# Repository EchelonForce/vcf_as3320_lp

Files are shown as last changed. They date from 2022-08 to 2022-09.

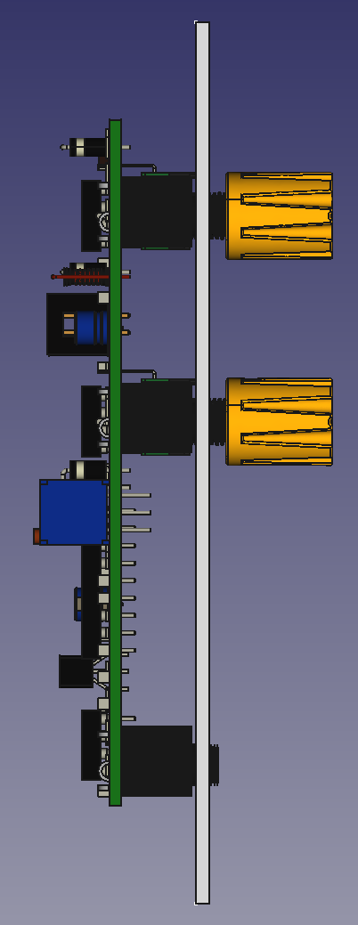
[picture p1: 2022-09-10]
front_panel_v1/render3.png

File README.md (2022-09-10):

# Eurorack Low Pass VCF AS3320

This is a design for a eurorack low pass VCF using the AS3320 VCF chip.

Full writeup here: https://www.robotdialogs.com/2022/09/eurorack-vcf-module-low-pass-filter.html

This work is licensed under a Creative Commons Attribution-NonCommercial-ShareAlike 4.0 International License. https://creativecommons.org/licenses/by-nc-sa/4.0/

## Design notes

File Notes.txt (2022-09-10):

https://electricdruid.net/multimode-filters-part-1-reconfigurable-filters/
https://electricdruid.net/multimode-filters-part-2-pole-mixing-filters/

Full datasheet: https://www.bustedgear.com/images/datasheets/CEM3320.pdf

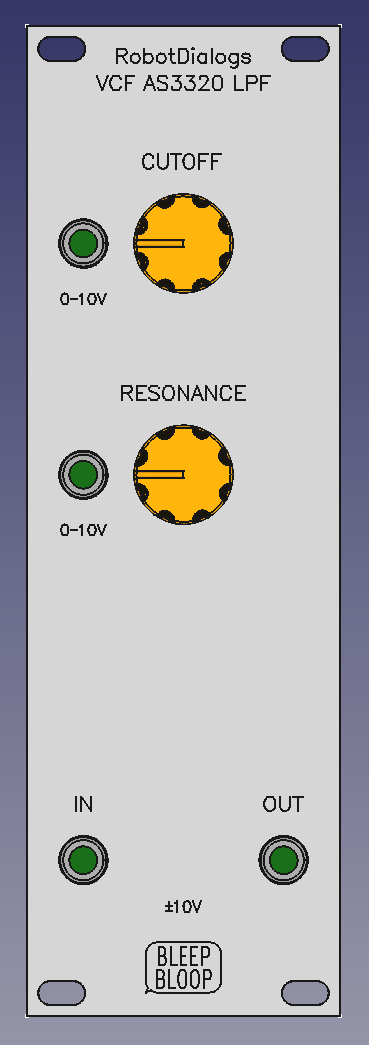
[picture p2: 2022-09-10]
front_panel_v1/render1.png

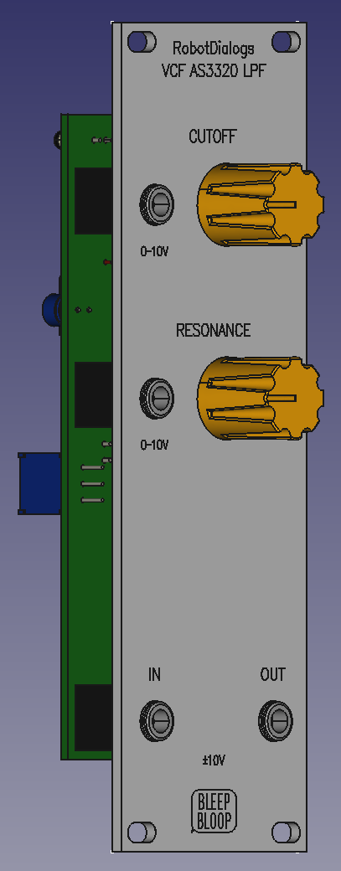
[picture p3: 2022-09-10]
front_panel_v1/render2.png

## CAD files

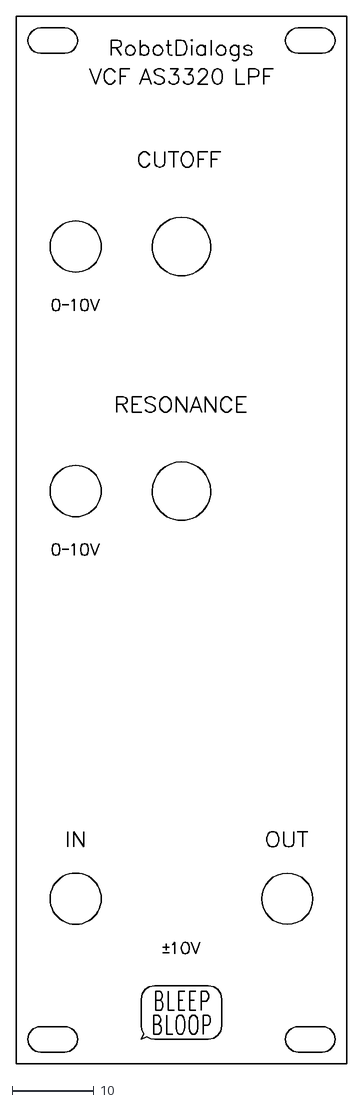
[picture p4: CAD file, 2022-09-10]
front_panel_v1/vcf_as3320_lpf_v1_front_panel_v1_engraving.dxf
40.5 x 128.4

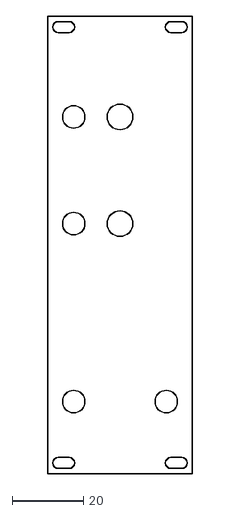
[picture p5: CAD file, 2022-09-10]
front_panel_v1/vcf_as3320_lpf_v1_front_panel_v1_no_engraving.dxf
40.6 x 128.5

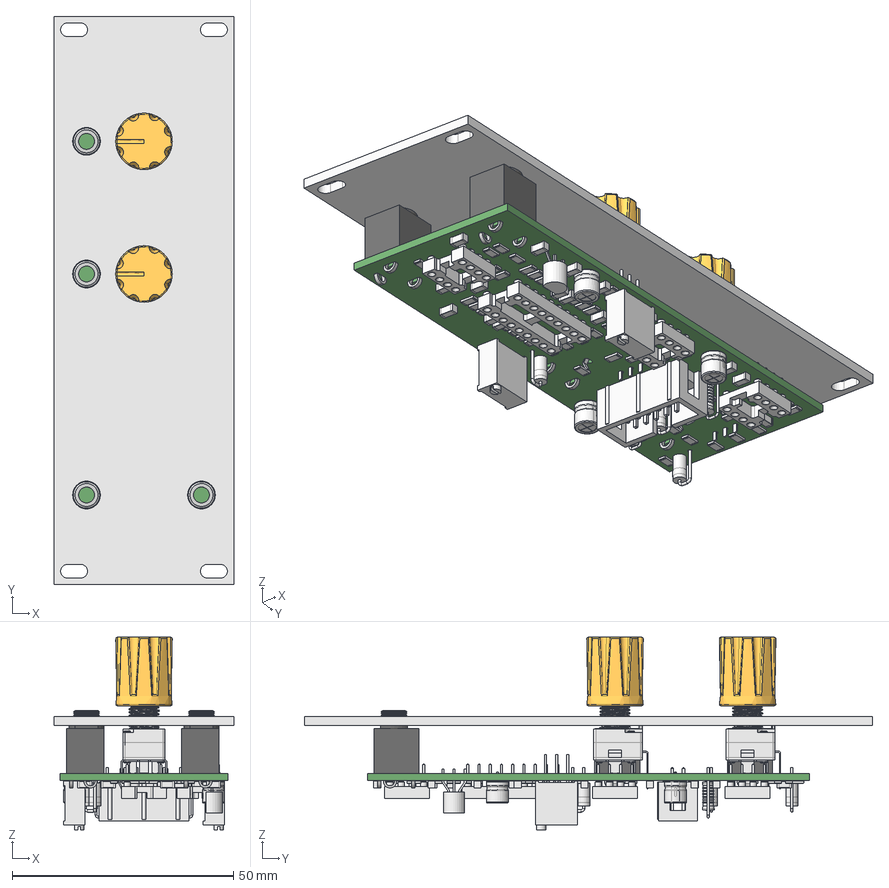
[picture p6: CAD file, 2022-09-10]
front_panel_v1/vcf_as3320_lpf_v1_front_panel_v1.FCStd
40.6 x 128.5 x 43.5 mm
vcf_as3320_lpf_v1 PCB

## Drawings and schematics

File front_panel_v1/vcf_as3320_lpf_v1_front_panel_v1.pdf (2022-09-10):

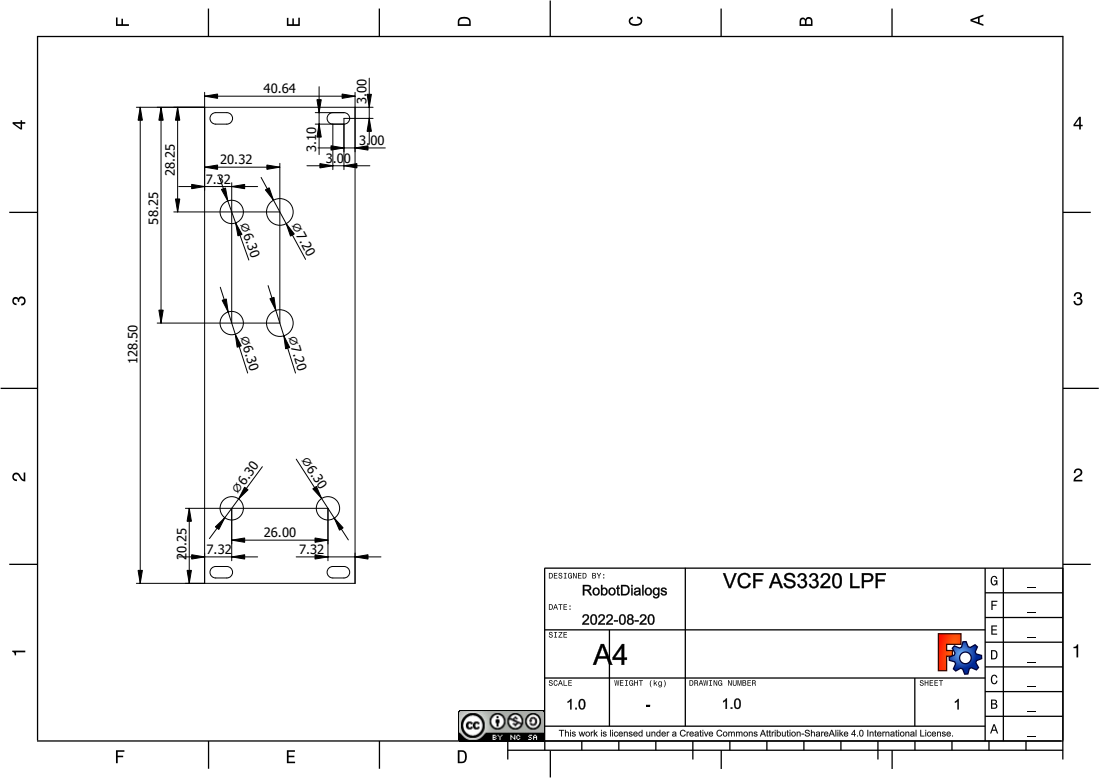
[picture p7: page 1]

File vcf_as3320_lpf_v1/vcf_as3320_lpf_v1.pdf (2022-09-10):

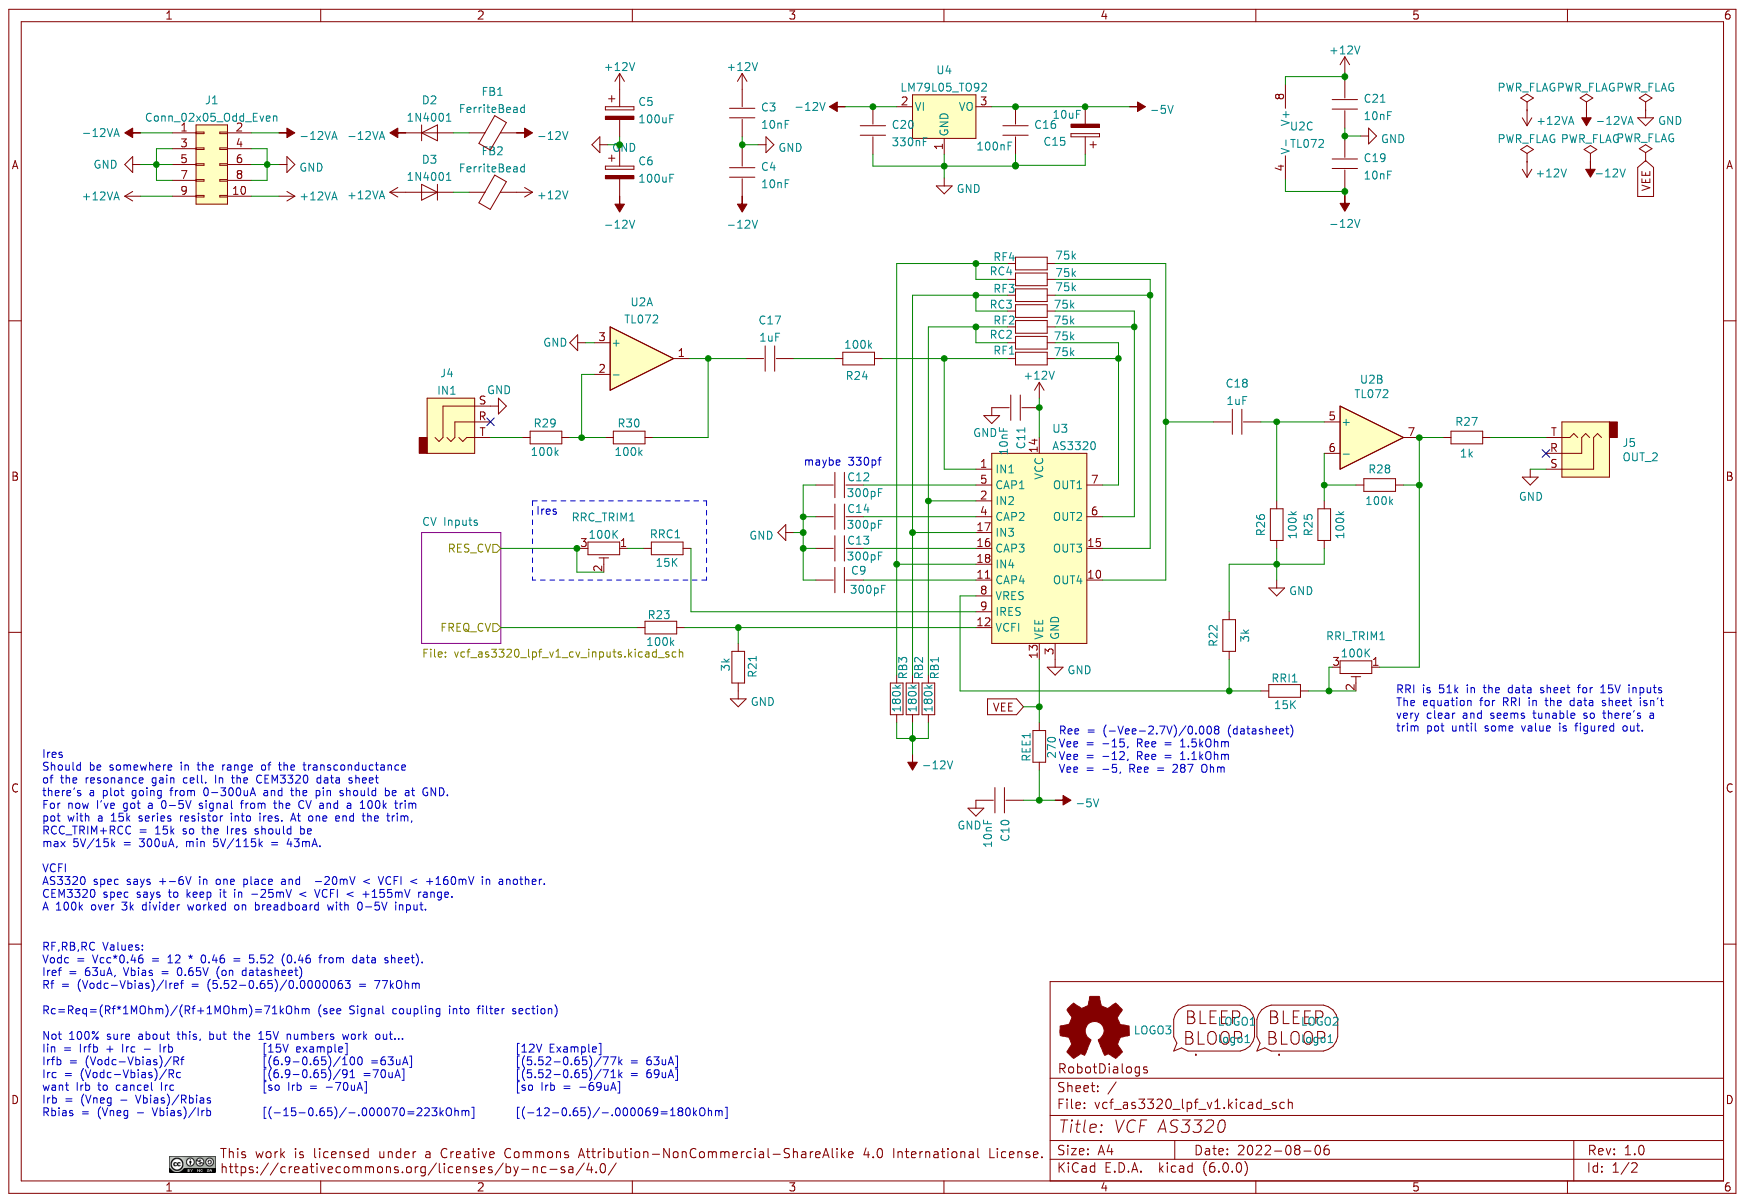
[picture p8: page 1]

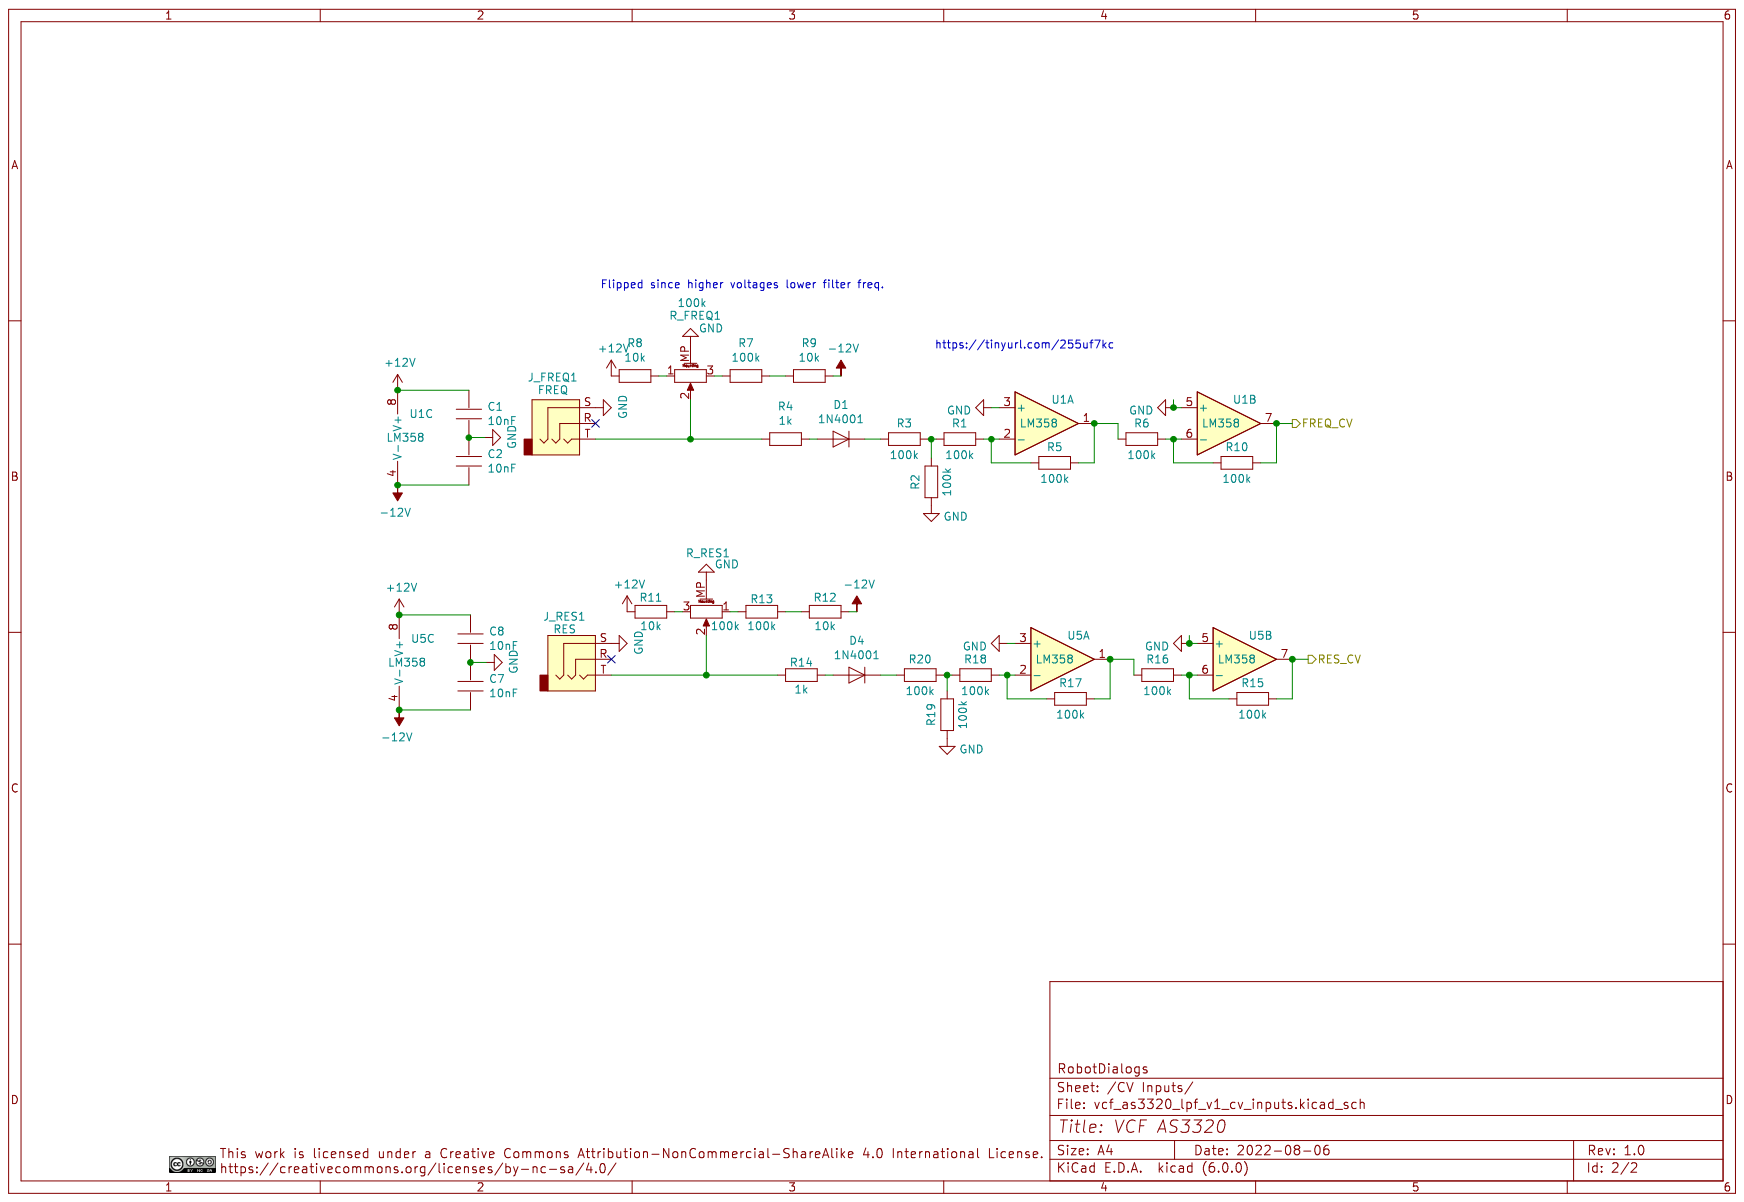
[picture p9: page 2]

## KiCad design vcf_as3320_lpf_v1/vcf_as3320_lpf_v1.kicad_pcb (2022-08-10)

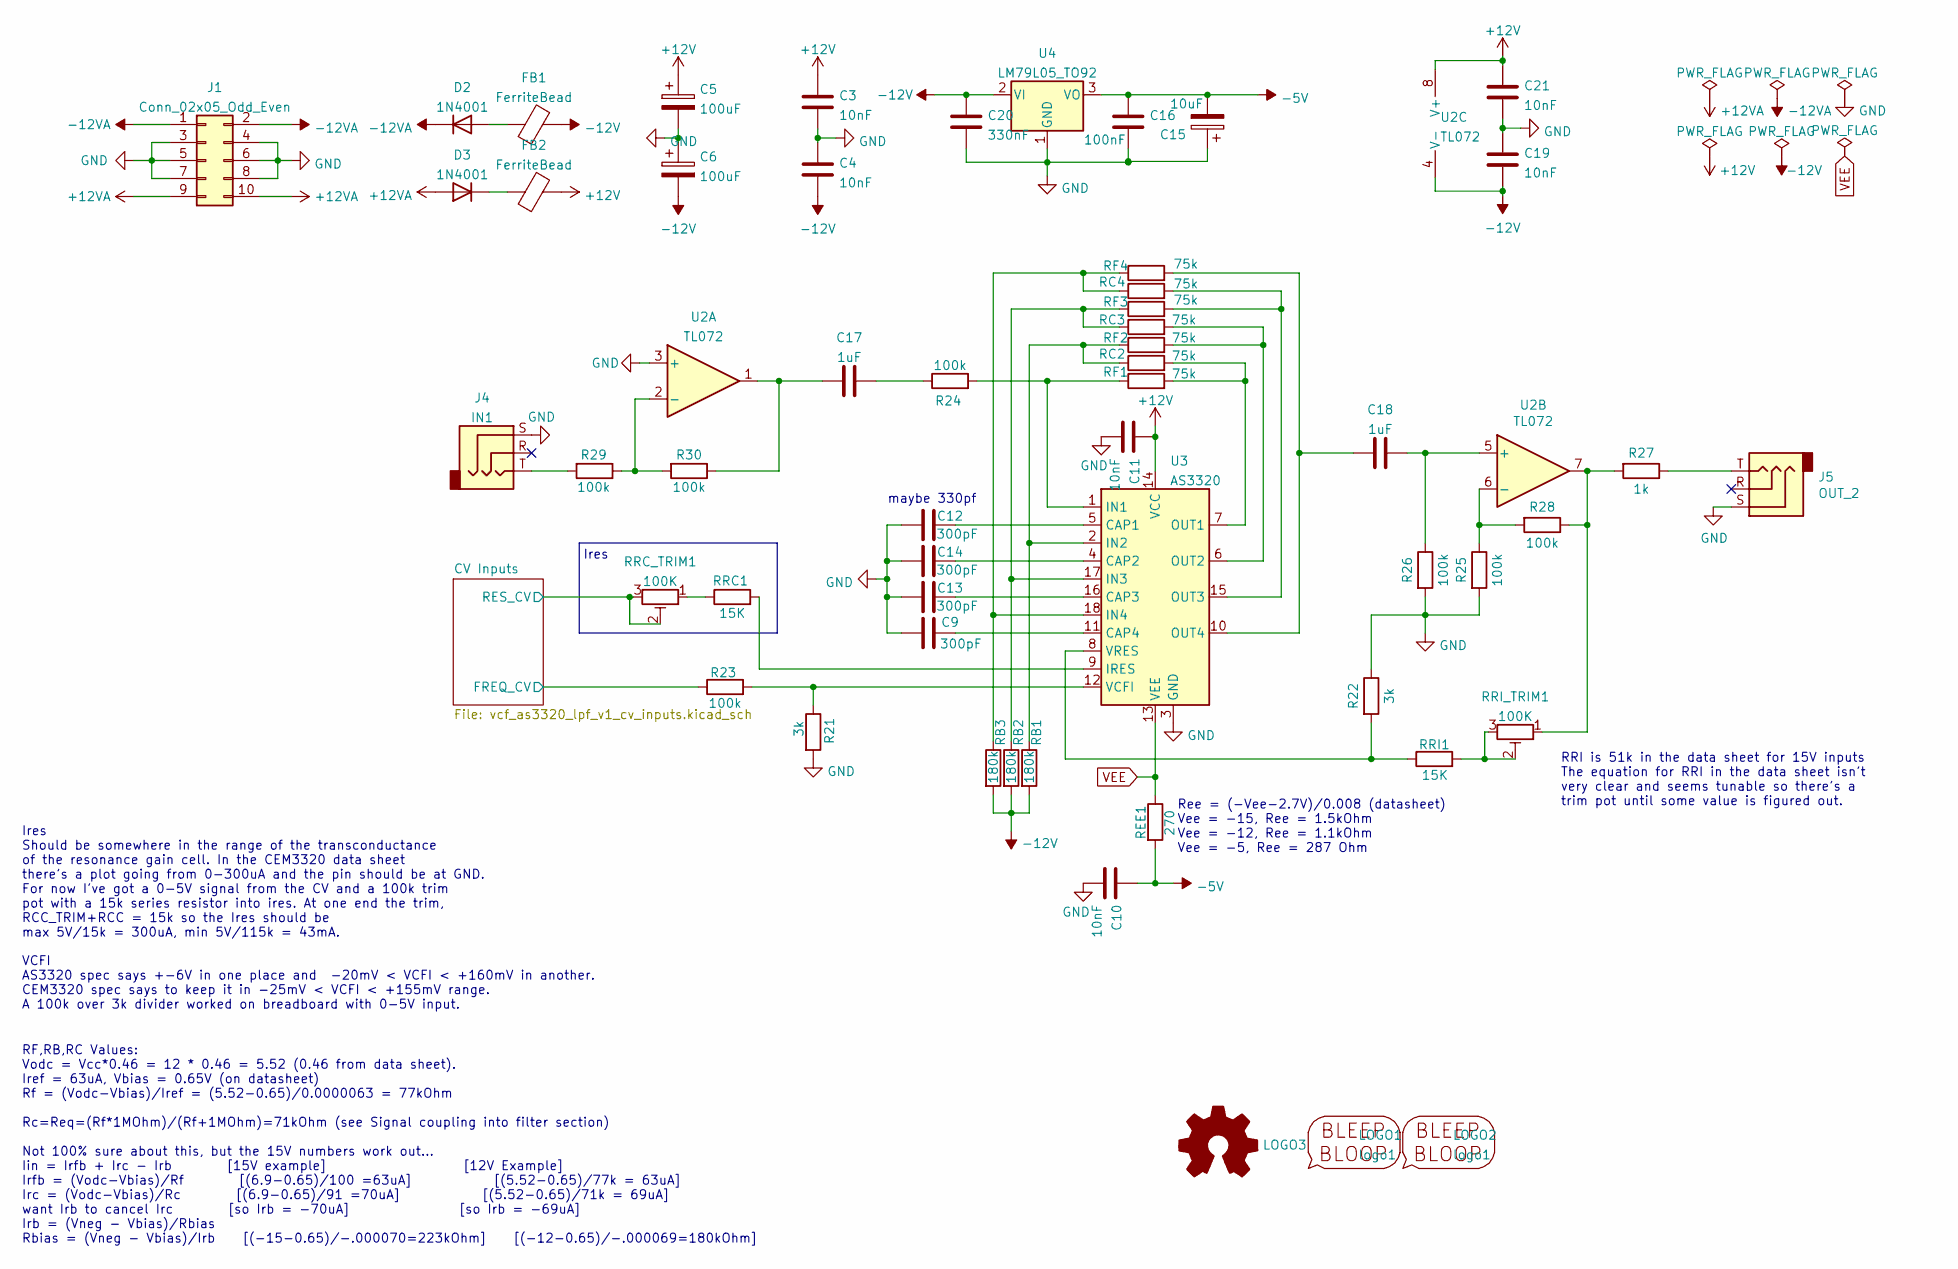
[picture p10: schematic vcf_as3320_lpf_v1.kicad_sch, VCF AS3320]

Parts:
C3, C4, C10, C11, C19, C21: 10nF; C_1206_3216Metric_Pad1.33x1.80mm_HandSolder
C5, C6: 100uF; CP_Radial_D5.0mm_P2.50mm
C9, C12, C13, C14: 300pF; C_1206_3216Metric_Pad1.33x1.80mm_HandSolder
C15: 10uF; CP_Radial_D5.0mm_P2.50mm
C16: 100nF; C_1206_3216Metric_Pad1.33x1.80mm_HandSolder
C17, C18: 1uF; C_1206_3216Metric_Pad1.33x1.80mm_HandSolder
C20: 330nF; C_1206_3216Metric_Pad1.33x1.80mm_HandSolder
D2, D3: 1N4001; D_A-405_P2.54mm_Vertical_KathodeUp
FB1, FB2: FerriteBead; L_Axial_L6.6mm_D2.7mm_P2.54mm_Vertical_Vishay_IM-2
J1: Conn_02x05_Odd_Even; IDC-Header_2x05_P2.54mm_Vertical
J4: IN1; Jack_3.5mm_MJ-355W_Vertical
J5: OUT_2; Jack_3.5mm_MJ-355W_Vertical
LOGO1: logo1; Logo1
LOGO2: logo1; Logo2
LOGO3: Logo_Open_Hardware_Small; OSHW-Symbol_6.7x6mm_SilkScreen
R21, R22: 3k; R_1206_3216Metric_Pad1.30x1.75mm_HandSolder
R23, R24, R25, R26, R28, R29, R30: 100k; R_1206_3216Metric_Pad1.30x1.75mm_HandSolder
R27: 1k; R_1206_3216Metric_Pad1.30x1.75mm_HandSolder
RB1, RB2, RB3: 180k; R_1206_3216Metric_Pad1.30x1.75mm_HandSolder
RC2, RC3, RC4: 75k; R_1206_3216Metric_Pad1.30x1.75mm_HandSolder
REE1: 270; R_1206_3216Metric_Pad1.30x1.75mm_HandSolder
RF1, RF2, RF3, RF4: 75k; R_1206_3216Metric_Pad1.30x1.75mm_HandSolder
RRC1: 15K; R_1206_3216Metric_Pad1.30x1.75mm_HandSolder
RRC_TRIM1: 100K; Potentiometer_Bourns_3296W_Vertical
RRI1: 15K; R_1206_3216Metric_Pad1.30x1.75mm_HandSolder
RRI_TRIM1: 100K; Potentiometer_Bourns_3296W_Vertical
U2: TL072; DIP-8_W7.62mm_Socket_LongPads
U3: AS3320; DIP-18_W7.62mm_Socket_LongPads
U4: LM79L05_TO92; TO-92_Inline_Wide

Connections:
+12V: C3.1, C5.1, C11.1, C21.1, FB2.2, U2.8 (V+), U3.14 (VCC); also elsewhere on the board
+12VA: D3.2 (A), J1.9, J1.10
-5V: C10.1, C15.2, C16.1, REE1.2, U4.3 (VO)
-12V: C4.2, C6.2, C19.2, C20.1, FB1.2, RB1.2, RB2.2, RB3.2, U2.4 (V-), U4.2 (VI); also elsewhere on the board
-12VA: D2.1 (K), J1.1, J1.2
/CV Inputs/FREQ_CV: R23.1; also elsewhere on the board
/CV Inputs/RES_CV: RRC_TRIM1.2, RRC_TRIM1.3; also elsewhere on the board
GND: C3.2, C4.1, C5.2, C6.1, C9.2, C10.2, C11.2, C12.2, C13.2, C14.2, C15.1, C16.2, C19.1, C20.2, C21.2, J1.3, J1.4, J1.5, J1.6, J1.7, J1.8, J4.S, J5.S, R21.2, R22.1, R25.2, R26.2, U2.3 (+), U3.3 (GND), U4.1 (GND); also elsewhere on the board
unnamed: C9.1, U3.11 (CAP4)
unnamed: C12.1, U3.5 (CAP1)
unnamed: C13.1, U3.16 (CAP3)
unnamed: C14.1, U3.4 (CAP2)
unnamed: C17.1, R24.1
unnamed: C17.2, R30.1, U2.1
unnamed: C18.1, R26.1, U2.5 (+)
unnamed: C18.2, RF4.2, U3.10 (OUT4)
unnamed: D2.2 (A), FB1.1
unnamed: D3.1 (K), FB2.1
unnamed: J4.T, R29.2
unnamed: J5.T, R27.1
unnamed: R22.2, RRI1.1, U3.8 (VRES)
unnamed: R21.1, R23.2, U3.12 (VCFI)
unnamed: R24.2, RF1.1, U3.1 (IN1)
unnamed: R27.2, R28.1, RRI_TRIM1.1, U2.7
unnamed: R25.1, R28.2, U2.6 (-)
unnamed: R29.1, R30.2, U2.2 (-)
unnamed: RB1.1, RC2.1, RF2.1, U3.2 (IN2)
unnamed: RB2.1, RC3.1, RF3.1, U3.17 (IN3)
unnamed: RB3.1, RC4.1, RF4.1, U3.18 (IN4)
unnamed: RC2.2, RF1.2, U3.7 (OUT1)
unnamed: RC3.2, RF2.2, U3.6 (OUT2)
unnamed: RC4.2, RF3.2, U3.15 (OUT3)
unnamed: RRC1.1, RRC_TRIM1.1
unnamed: RRC1.2, U3.9 (IRES)
unnamed: RRI1.2, RRI_TRIM1.2, RRI_TRIM1.3
VEE: REE1.1, U3.13 (VEE)

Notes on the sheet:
maybe 330pf
VCFI AS3320 spec says +-6V in one place and -20mV < VCFI < +160mV in another. CEM3320 spec says to keep it in -25mV < VCFI < +155mV range. A 100k over 3k divider worked on breadboard with 0-5V input.
RRI is 51k in the data sheet for 15V inputs The equation for RRI in the data sheet isn't very clear and seems tunable so there's a trim pot until some value is figured out.
RF,RB,RC Values: Vodc = Vcc*0.46 = 12 * 0.46 = 5.52 (0.46 from data sheet). Iref = 63uA, Vbias = 0.65V (on datasheet) Rf = (Vodc-Vbias)/Iref = (5.52-0.65)/0.0000063 = 77kOhm Rc=Req=(Rf*1MOhm)/(Rf+1MOhm)=71kOhm (see Signal coupling into filter section) Not 100% sure about this, but the 15V numbers w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
Ires Should be somewhere in the range of the transconductance of the resonance gain cell. In the CEM3320 data sheet there's a plot going from 0-300uA and the pin should be at GND. For now I've got a 0-5V signal from the CV and a 100k trim pot with a 15k series resistor into ires. At one end the tri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
Ires
Ree = (-Vee-2.7V)/0.008 (datasheet) Vee = -15, Ree = 1.5kOhm Vee = -12, Ree = 1.1kOhm Vee = -5, Ree = 287 Ohm

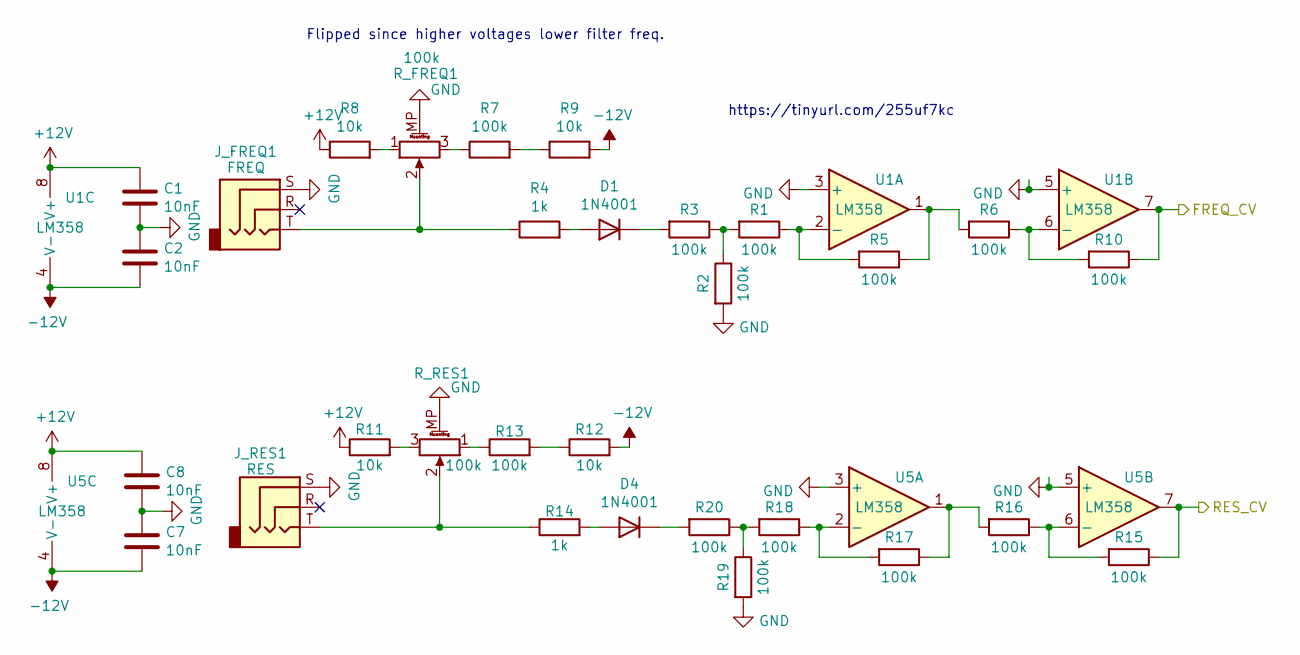
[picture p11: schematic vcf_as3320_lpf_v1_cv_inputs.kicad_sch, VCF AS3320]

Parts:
C1, C2, C7, C8: 10nF; C_1206_3216Metric_Pad1.33x1.80mm_HandSolder
D1, D4: 1N4001; D_A-405_P2.54mm_Vertical_KathodeUp
J_FREQ1: FREQ; Jack_3.5mm_MJ-355W_Vertical
J_RES1: RES; Jack_3.5mm_MJ-355W_Vertical
R1, R2, R3, R5, R6, R7, R10, R13, R15, R16, R17, R18, R19, R20: 100k; R_1206_3216Metric_Pad1.30x1.75mm_HandSolder
R4, R14: 1k; R_1206_3216Metric_Pad1.30x1.75mm_HandSolder
R8, R9, R11, R12: 10k; R_1206_3216Metric_Pad1.30x1.75mm_HandSolder
R_FREQ1: 100k; Potentiometer_Alpha_RD901F-40-00D_Single_Vertical_w_3d
R_RES1: 100k; Potentiometer_Alpha_RD901F-40-00D_Single_Vertical_w_3d
U1, U5: LM358; DIP-8_W7.62mm_Socket_LongPads

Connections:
+12V: C1.2, C8.2, R8.1, R11.1, U1.8 (V+), U5.8 (V+); also elsewhere on the board
-12V: C2.1, C7.1, R9.2, R12.2, U1.4 (V-), U5.4 (V-); also elsewhere on the board
/CV Inputs/FREQ_CV: R10.1, U1.7; also elsewhere on the board
/CV Inputs/RES_CV: R15.1, U5.7; also elsewhere on the board
GND: C1.1, C2.2, C7.2, C8.1, J_FREQ1.S, J_RES1.S, R2.2, R19.2, R_FREQ1.MP (MountPin), R_RES1.MP (MountPin), U1.3 (+), U1.5 (+), U5.3 (+), U5.5 (+); also elsewhere on the board
unnamed: D1.1 (K), R3.2
unnamed: D1.2 (A), R4.2
unnamed: D4.1 (K), R20.2
unnamed: D4.2 (A), R14.2
unnamed: J_FREQ1.T, R4.1, R_FREQ1.2
unnamed: J_RES1.T, R14.1, R_RES1.2
unnamed: R1.1, R5.2, U1.2 (-)
unnamed: R1.2, R2.1, R3.1
unnamed: R6.1, R10.2, U1.6 (-)
unnamed: R5.1, R6.2, U1.1
unnamed: R7.1, R_FREQ1.3
unnamed: R7.2, R9.1
unnamed: R8.2, R_FREQ1.1
unnamed: R11.2, R_RES1.3
unnamed: R13.1, R_RES1.1
unnamed: R12.1, R13.2
unnamed: R15.2, R16.1, U5.6 (-)
unnamed: R16.2, R17.1, U5.1
unnamed: R17.2, R18.1, U5.2 (-)
unnamed: R18.2, R19.1, R20.1

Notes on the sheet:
https://tinyurl.com/255uf7kc
Flipped since higher voltages lower filter freq.

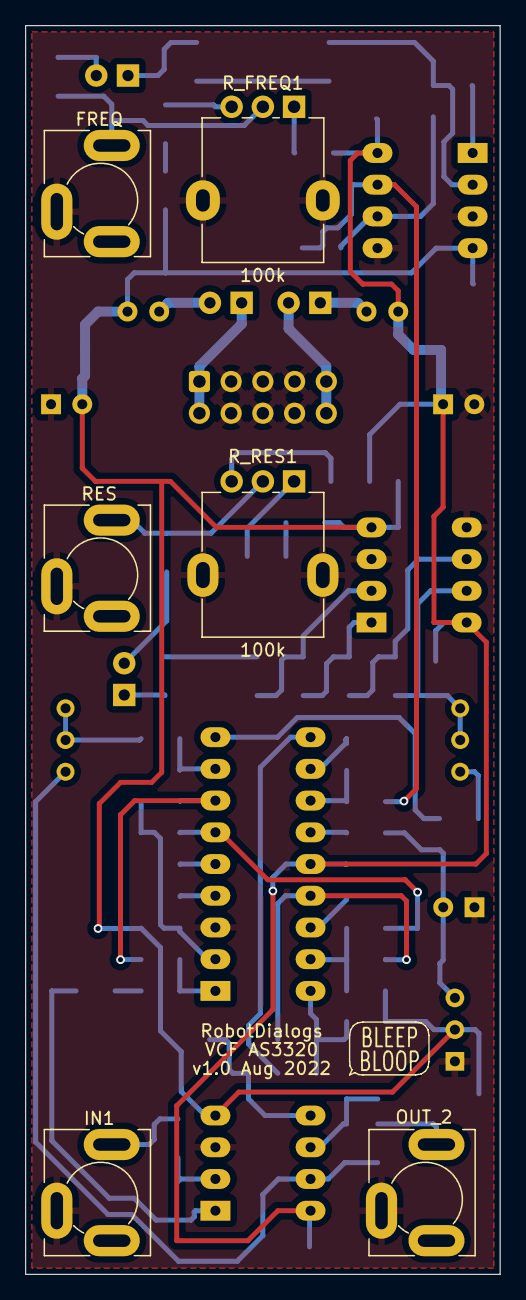
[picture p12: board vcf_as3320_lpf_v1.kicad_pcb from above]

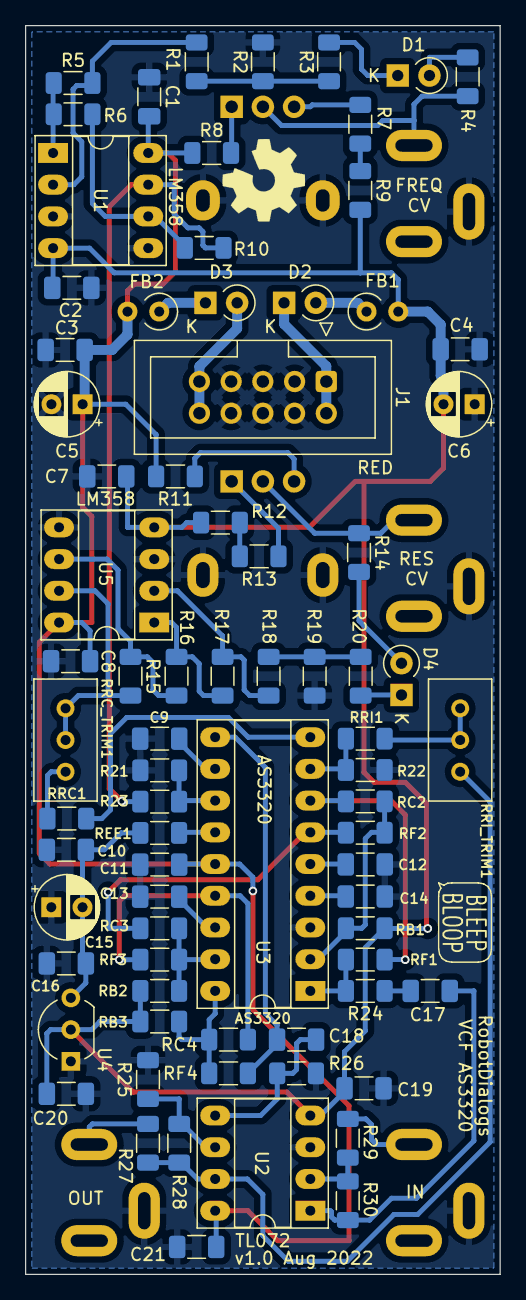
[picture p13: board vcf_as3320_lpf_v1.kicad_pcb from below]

Board: 2 copper layers, 38.0 x 100.0 mm, 87 parts (79 on the bottom side), 56 nets.

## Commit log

2022-08-04 Schematic draft done and breadboard verified
    [vcf_as3320_lpf_v1.kicad_pcb, vcf_as3320_lpf_v1.kicad_sch, vcf_as3320_lpf_v1_cv_inputs.kicad_sch]
2022-08-06 Draft layout done no routing
    [vcf_as3320_lpf_v1.kicad_pcb, vcf_as3320_lpf_v1.kicad_sch, vcf_as3320_lpf_v1_cv_inputs.kicad_sch]
2022-08-06 Draft routing done
    [vcf_as3320_lpf_v1.kicad_pcb]
2022-08-10 Geographic rename, silkscreen cleanup
    [vcf_as3320_lpf_v1.kicad_pcb, vcf_as3320_lpf_v1.kicad_sch, vcf_as3320_lpf_v1_cv_inputs.kicad_sch]
2022-09-10 panelized outputs and notes
    [vcf_as3320_lpf_v1_panelized.kicad_pcb]
2022-09-10 Front Panel design files
    [vcf_as3320_lpf_v1_front_panel_v1.FCStd, vcf_as3320_lpf_v1_front_panel_v1_engraving.dxf, vcf_as3320_lpf_v1_front_panel_v1_no_engraving.dxf]
